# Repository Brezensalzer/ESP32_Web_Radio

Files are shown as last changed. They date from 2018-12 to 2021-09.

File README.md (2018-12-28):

This code is based on the great project from Nick Koumaris here: https://educ8s.tv/esp32-internet-radio/ .
There is also an instructable page: https://www.instructables.com/id/Internet-Radio-Using-an-ESP32/

Code changes:
* the station list is fetched on startup from a remote web server
* multitasking and buffering - the mp3 player code is running in a separate task (freeRTOS), the mp3 chunks are buffered in a queue
* Nextion HMI adapted to my 2.8" version of the display. Text is displayed dynamically with an art deco font. Buttons and a slider are used as controls (vs. physical buttons in the original project)
* Nextion display is connected to "Serial2" (ESP32 pins 16 RXD & 17 TXD) - "Serial" is connected to the USB converter and gives trouble when uploading a sketch.
* Station and volume control with rotary encoders

Used libraries:
* https://github.com/baldram/ESP_VS1053_Library
* https://github.com/itead/ITEADLIB_Arduino_Nextion
* Rotary encoder code from https://github.com/Edzelf/ESP32-Radio

Hardware:
* ESP32 board (Node32s)
* Nextion Display NX3224T028_011
* Level shifter 5V - 3.3V, 2 channels: Nextion runs on 5V, ESP32 (RX pin!) on 3.3V 
* MP3 module "LC Technology VS1003/1053 MP3 CODEC"
* Adafruit Stereo 2.1W Class D Audio Amplifier - TPA2012 (no noise!)
* Adafruit Speaker - 3" Diameter - 4 Ohm 3 Watt, 2x
* KY-040 Rotary Encoder, 2x

Plan:
* building a wooden artdeco enclosure: http://www.vintageradio.nl/radio%27s/rubis_type_72_engels.htm

3D Drawings:
* FreeCAD, step and stl files are now available.
* My first version will be 3D printed
* Youtube Video: https://youtu.be/TEc8J43VpVg

<p align="center">
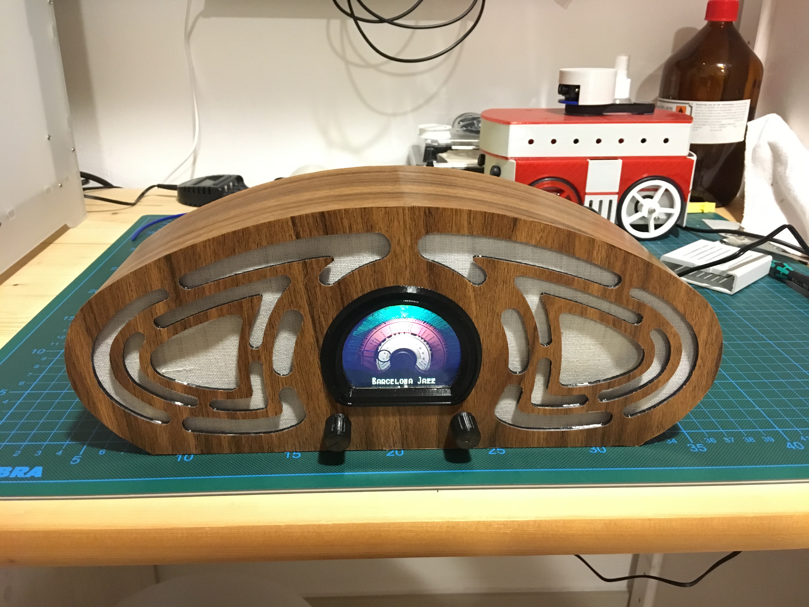
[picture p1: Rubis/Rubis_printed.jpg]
  
</p>

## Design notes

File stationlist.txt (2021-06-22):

B5 aktuell;http://br-b5aktuell-live.cast.addradio.de/br/b5aktuell/live/mp3/mid
BR Klassik;http://br-brklassik-live.cast.addradio.de/br/brklassik/live/mp3/mid
Bayern 2;http://br-br2-sued.cast.addradio.de/br/br2/sued/mp3/mid
Deutschlandfunk Kultur;http://st02.dlf.de/dlf/02/128/mp3/stream.mp3
Jazz Radio BCN;http://node-22.zeno.fm:80/u40kkya8hg8uv
Abacus Jazz;http://185.80.221.113:8034/stream
SmoothJazz;http://sj128.hnux.com/
City Jazz Radio;http://85.17.122.32:8252/stream

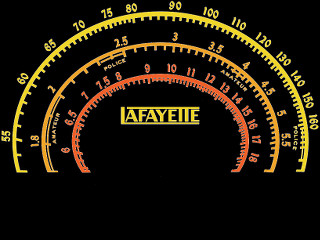
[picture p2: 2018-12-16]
GUI/lafayettedial.jpg

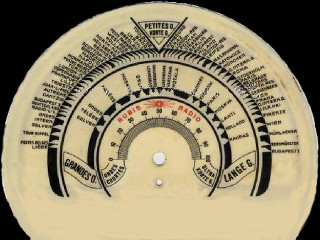
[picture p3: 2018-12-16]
GUI/rubis70_dial.jpg

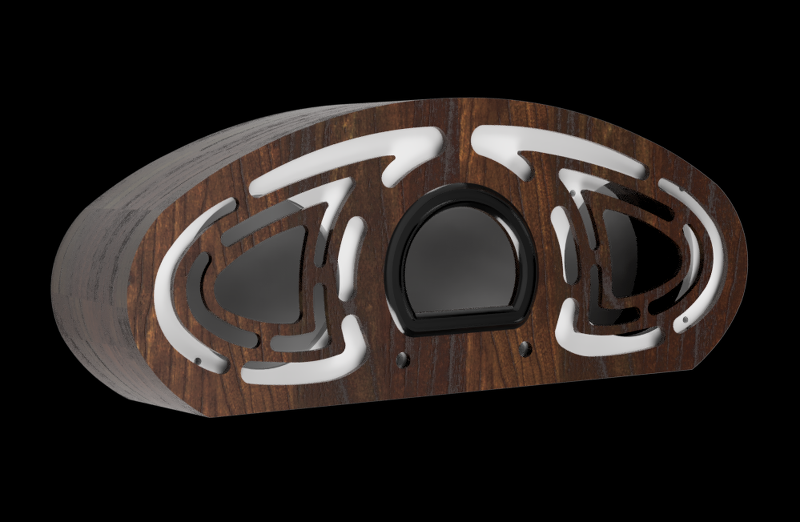
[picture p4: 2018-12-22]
Rubis/Rubis_70_render.png

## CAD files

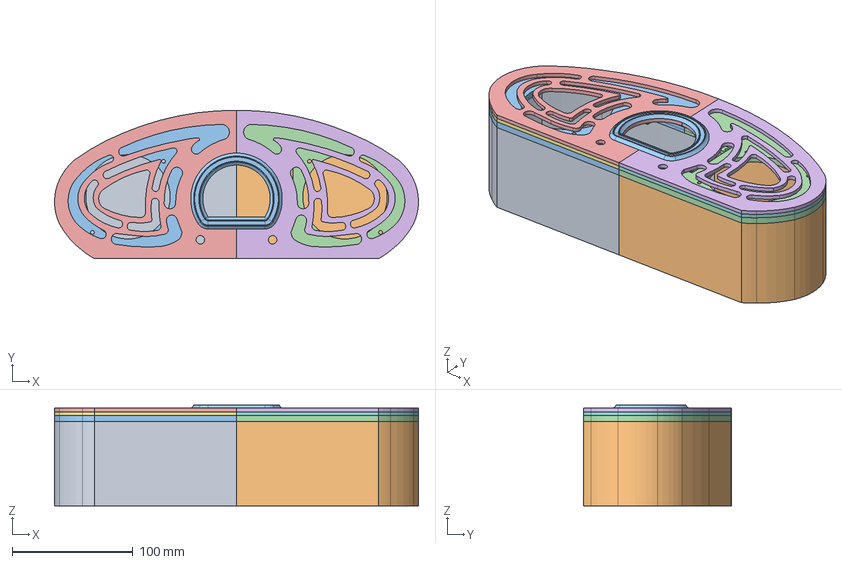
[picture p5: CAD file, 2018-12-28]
Rubis/rubis_korpus.FCStd
302.1 x 123.1 x 83.5 mm
Korpus_links
Korpus_rechts
Front_links
Front_rechts
Blende_links
Blende_rechts
Korpus_links001
Korpus_rechts001
Rückwand_links
Rückwand_rechts

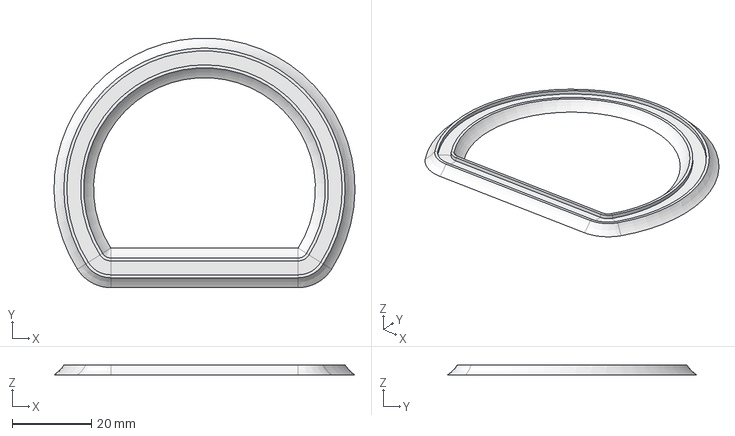
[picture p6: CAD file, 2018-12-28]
Rubis/Displayrahmen.step
76.0 x 62.9 x 2.50 mm

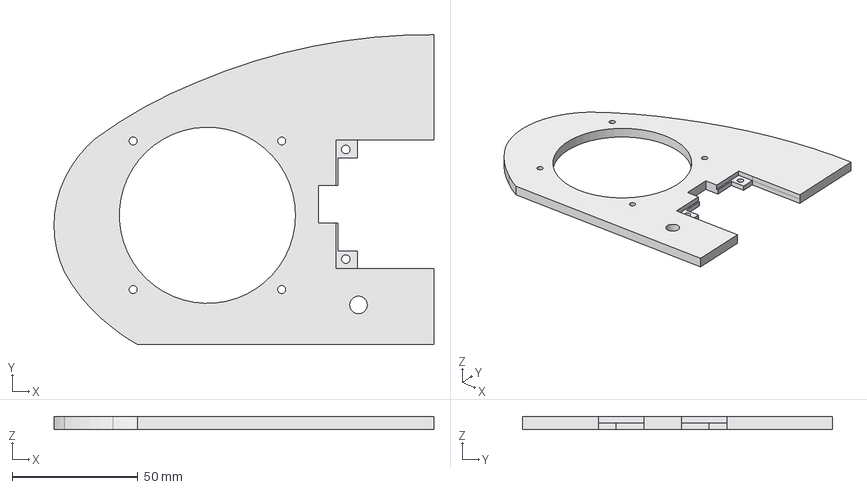
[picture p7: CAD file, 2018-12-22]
Rubis/Front_links.step
151.0 x 123.1 x 5.00 mm

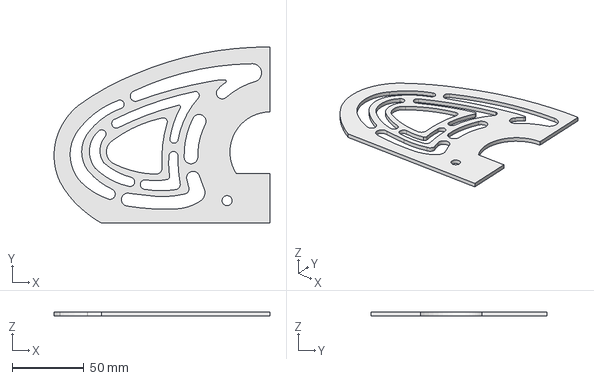
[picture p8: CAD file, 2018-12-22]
Rubis/Blende_links.step
151.0 x 123.1 x 3.00 mm

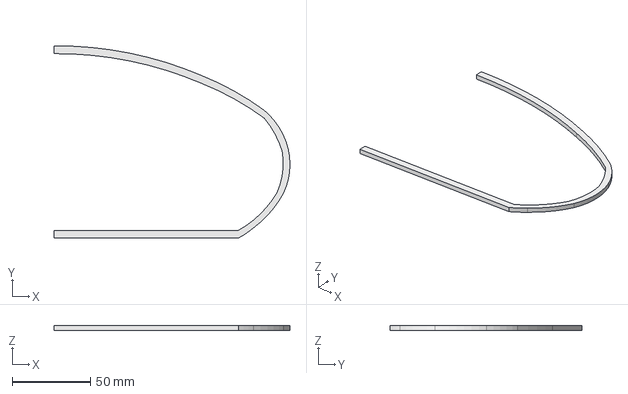
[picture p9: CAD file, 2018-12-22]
Rubis/Montage_rechts.step
151.0 x 123.1 x 3.00 mm

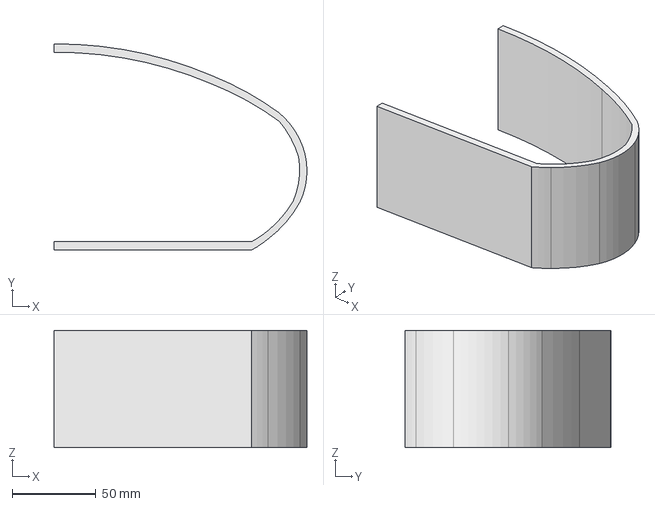
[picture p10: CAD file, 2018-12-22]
Rubis/Korpus_rechts.step
151.0 x 123.1 x 70.0 mm

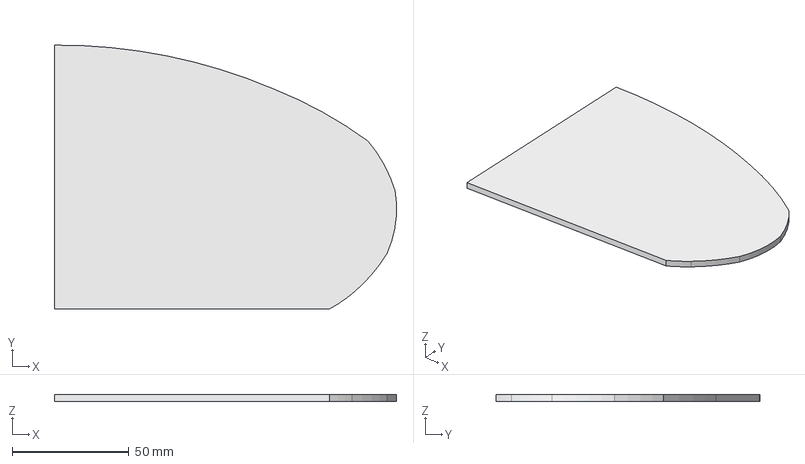
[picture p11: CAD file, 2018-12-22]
Rubis/Back_rechts.step
146.6 x 113.1 x 3.00 mm

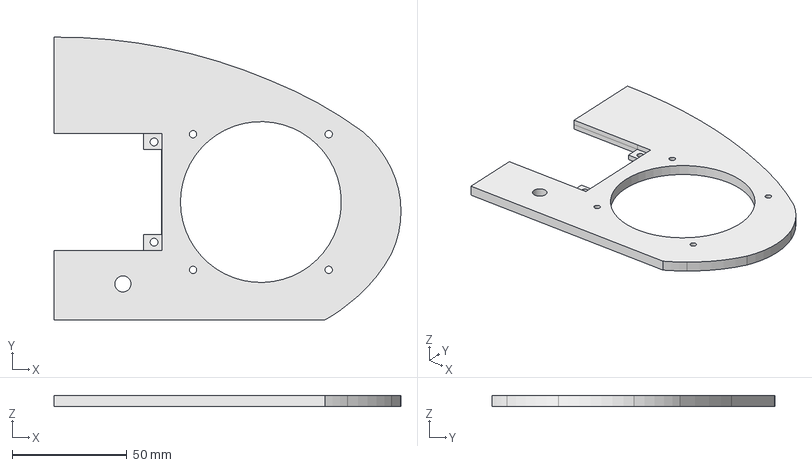
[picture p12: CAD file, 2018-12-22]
Rubis/Front_rechts.step
151.0 x 123.1 x 5.00 mm

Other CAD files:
Rubis/Montage_links.step
Rubis/Korpus_links.step
Rubis/Back_links.step
Rubis/Blende_rechts.step
Rubis/Back_links.stl
Rubis/Back_rechts.stl
Rubis/Blende_links.stl
Rubis/Blende_rechts.stl
Rubis/Displayrahmen.stl
Rubis/Front_links.stl
Rubis/Front_rechts.stl
Rubis/Korpus_links.stl
Rubis/Korpus_rechts.stl
Rubis/Montage_links.stl
Rubis/Montage_rechts.stl

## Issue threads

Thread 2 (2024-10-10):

The sketch doesn't compile

ovidiu169, 2024-10-10:
C:\Users\Ovidiu\Documents\Arduino\libraries\ESP32_Web_Radio-master\ESP32_Web_Radio\ESP32_Web_Radio.ino:15:10: fatal error: credentials.h: No such file or directory
   15 | #include <credentials.h>
      |          ^~~~~~~~~~~~~~~
compilation terminated.
exit status 1

Compilation error: credentials.h: No such file or directory

What can I do ?!?

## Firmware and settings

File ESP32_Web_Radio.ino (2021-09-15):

// ESP32_Web_Radio.ino
//
// Project based on
// ESP32 Internet Radio Project     v1.00 
// http://educ8s.tv/esp32-internet-radio

#include <VS1053.h>
#include <WiFi.h>
#include <WebServer.h>
#include <ESPmDNS.h>
#include <HTTPClient.h>
#include <esp_wifi.h>
#include <Nextion.h>
#include <Arduino.h>
#include <credentials.h>
#include "RadioStation.h"

#define DEBUG true
#define LOGSERVER      "192.168.1.4"
#define UDP_LOGGER
#include <SimpleUDPLogger.h>
const char* ssid = mySSID;
const char* pass = myPASSWORD;
const char* host = "esp32radio";

#define FILESYSTEM SPIFFS
#include <SPIFFS.h>
File fsUploadFile;
WebServer server(80);

//------------------------------------------------------------------------------
// mp3 module
//------------------------------------------------------------------------------
  #define VS1053_CS    32 
  #define VS1053_DCS   33  
  #define VS1053_DREQ  35 
  #define MIN_VOLUME  70
  #define MAX_VOLUME  100
  uint8_t volume = 82; // volume level 0-100
  uint8_t mp3buff[32];   // vs1053 likes 32 bytes at a time
  
  VS1053 player(VS1053_CS, VS1053_DCS, VS1053_DREQ);
  
  //------------------------------------------------------------------------------
  void initMP3Decoder()
  //------------------------------------------------------------------------------
    {
      player.begin();
      player.switchToMp3Mode(); // optional, some boards require this
      player.setVolume(volume);
    }

//------------------------------------------------------------------------------
// freertos multitasking and queueing
//------------------------------------------------------------------------------
  #define QUEUELENGTH 1024
  QueueHandle_t xQueueMp3;
  
  // Dimensions the buffer that the task being created will use as its stack.
  // NOTE:  This is the number of bytes the stack will hold, not the number of
  // words as found in vanilla FreeRTOS.
  #define STACK_SIZE 65536
  TaskHandle_t xHandle = NULL;
  
  //------------------------------------------------------------------------------
  void task_mp3play(void * pvParameters)
  //------------------------------------------------------------------------------
  {
    byte        mp3chunk[32];
    uint16_t    queue_depth;

    // loop forever
    while(true)
    {
        // Receive a message on the created queue.  Block for 10 ticks if a
        // message is not immediately available.
        if( xQueueReceive( xQueueMp3, &( mp3chunk ), ( TickType_t ) 10 ) )
        {
             // we now can consume mp3chunk
             player.playChunk(mp3chunk, 32);
             yield();
        }
    }
  }
  
  //------------------------------------------------------------------------------
  void mp3Flush()   // clear queue from previous station
  //------------------------------------------------------------------------------
  {
      char rc;
      while(rc != pdPASS)
          rc = xQueueReset(xQueueMp3);
  }

//------------------------------------------------------------------------------
// radio stations
//------------------------------------------------------------------------------
  StationList stations;

//------------------------------------------------------------------------------
// Nextion
//------------------------------------------------------------------------------
  // don't use UART0, conflict with sketch upload
  // use UART2 on Pins 16 RXD & 17 TXD
  // has to be changed in NexConfig.h (!)
  // #define nexSerial Serial2
  
  NexText t0 = NexText(0, 2, "t0");  

//------------------------------------------------------------------------------
// Rotary Encoders
// copied from https://github.com/Edzelf/ESP32-Radio
//------------------------------------------------------------------------------
  #define sv DRAM_ATTR static volatile    // alias

  //-----------------------------------------------------------------------------
  // radio station
  //-----------------------------------------------------------------------------
  #define ENC_STATION_CLK_PIN 21
  #define ENC_STATION_DT_PIN 22
  sv int16_t    rotationcount_station = 0;
  int16_t       oldcount_station = 0;

  //-----------------------------------------------------------------------------
  static void IRAM_ATTR isr_enc_station()
  //-----------------------------------------------------------------------------
  {
    sv uint32_t     old_state = 0x0001 ;                          // Previous state
    sv int16_t      locrotcount = 0 ;                             // Local rotation count
    uint8_t         act_state = 0 ;                               // The current state of the 2 PINs
    uint8_t         inx ;                                         // Index in enc_state
    sv const int8_t enc_states [] =                               // Table must be in DRAM (iram safe)
    { 0,                    // 00 -> 00
      -1,                   // 00 -> 01                           // dt goes HIGH
      1,                    // 00 -> 10
      0,                    // 00 -> 11
      1,                    // 01 -> 00                           // dt goes LOW
      0,                    // 01 -> 01
      0,                    // 01 -> 10
      -1,                   // 01 -> 11                           // clk goes HIGH
      -1,                   // 10 -> 00                           // clk goes LOW
      0,                    // 10 -> 01
      0,                    // 10 -> 10
      1,                    // 10 -> 11                           // dt goes HIGH
      0,                    // 11 -> 00
      1,                    // 11 -> 01                           // clk goes LOW
      -1,                   // 11 -> 10                           // dt goes HIGH
      0                     // 11 -> 11
    } ;
    // Read current state of CLK, DT pin. Result is a 2 bit binary number: 00, 01, 10 or 11.
    act_state = ( digitalRead ( ENC_STATION_CLK_PIN ) << 1 ) +
                  digitalRead ( ENC_STATION_DT_PIN ) ;
    inx = ( old_state << 2 ) + act_state ;                        // Form index in enc_states
    locrotcount += enc_states[inx] ;                              // Get delta: 0, +1 or -1
    if ( locrotcount == 4 )
    {
      rotationcount_station++ ;                                   // Divide by 4
      locrotcount = 0 ;
    }
    else if ( locrotcount == -4 )
    {
      rotationcount_station-- ;                                   // Divide by 4
      locrotcount = 0 ;
    }
    old_state = act_state ;                                       // Remember current status
  }

  //-----------------------------------------------------------------------------
  // volume
  //-----------------------------------------------------------------------------
  #define ENC_VOLUME_CLK_PIN 25
  #define ENC_VOLUME_DT_PIN 26
  sv int16_t    rotationcount_volume = volume;
  int16_t       oldcount_volume = 0;

  //-----------------------------------------------------------------------------
  static void IRAM_ATTR isr_enc_volume()
  //-----------------------------------------------------------------------------
  {
    sv uint32_t     old_state = 0x0001 ;                          // Previous state
    sv int16_t      locrotcount = 0 ;                             // Local rotation count
    uint8_t         act_state = 0 ;                               // The current state of the 2 PINs
    uint8_t         inx ;                                         // Index in enc_state
    sv const int8_t enc_states [] =  { 0,-1,1,0,1,0,0,-1,-1,0,0,1,0,1,-1,0 } ;
    // Read current state of CLK, DT pin. Result is a 2 bit binary number: 00, 01, 10 or 11.
    act_state = ( digitalRead ( ENC_VOLUME_CLK_PIN ) << 1 ) +
                  digitalRead ( ENC_VOLUME_DT_PIN ) ;
    inx = ( old_state << 2 ) + act_state ;                        // Form index in enc_states
    locrotcount += enc_states[inx] ;                              // Get delta: 0, +1 or -1
    if ( locrotcount == 4 )
    {
      rotationcount_volume++ ;                                    // Divide by 4
      locrotcount = 0 ;
    }
    else if ( locrotcount == -4 )
    {
      rotationcount_volume-- ;                                    // Divide by 4
      locrotcount = 0 ;
    }
    old_state = act_state ;                                       // Remember current status
  }

  //------------------------------------------------------------------------------
  void encoderStation_loop() 
  //------------------------------------------------------------------------------
  {
    //lets see if anything changed
    if ( rotationcount_station != oldcount_station )
    {
      if ( rotationcount_station > stations.numStations )
      {
        rotationcount_station = 0;
      }
      if ( rotationcount_station < 0 )
      {
        rotationcount_station = stations.numStations;
      }
      oldcount_station = rotationcount_station;
      stations.radioStation = rotationcount_station;  
    }
  }
  
  //------------------------------------------------------------------------------
  void encoderVolume_loop() 
  //------------------------------------------------------------------------------
  {
    //lets see if anything changed
    if ( rotationcount_volume != oldcount_volume )
    {
      if ( rotationcount_volume > MAX_VOLUME )
      {
        rotationcount_volume = MAX_VOLUME;
      }
      if ( rotationcount_volume < MIN_VOLUME )
      {
        rotationcount_volume = MIN_VOLUME;
      }
      oldcount_volume = rotationcount_volume;
      volume = (int) rotationcount_volume;
      player.setVolume(volume); 
      UDP_LOG_INFO("set volume to %lu", volume);
    }
  }

//------------------------------------------------------------------------------
// Network
//------------------------------------------------------------------------------
  HTTPClient http;
  WiFiClient * client; 

  //------------------------------------------------------------------------------
  void connectToWIFI()
  //------------------------------------------------------------------------------
  {
    if(DEBUG) {Serial.print("Connecting to Wifi");}
    WiFi.mode(WIFI_STA);
    WiFi.persistent(false);
    WiFi.begin(ssid, pass);
    while (WiFi.status() != WL_CONNECTED) 
    {
      if(DEBUG) {Serial.print(".");}
      delay(500);
    }
    if(DEBUG) {Serial.println("\nWifi connected");}  
  }

  //------------------------------------------------------------------------------
  void station_connect (int station_no ) 
  //------------------------------------------------------------------------------
  {
    if (http.connected())
    {
      http.end(); // stop old connection
    }
    boolean isConnected = false;

    char rc[4];
    int httpCode;  
    char url[250];
    const char* headerNames[] = { "Location" };
    String Location;
    int pos;
    
    if(DEBUG) { Serial.println(stations.station[station_no].label); }
    if(DEBUG) { Serial.println(stations.station[station_no].url); }
    UDP_LOG_INFO(stations.station[station_no].label);      
    UDP_LOG_INFO(stations.station[station_no].url);

    t0.setText(stations.station[station_no].label);                 
    
    //-------------------------------
    //--- check for http redirect ---
    //-------------------------------
    http.begin(stations.station[station_no].url);
    http.collectHeaders(headerNames, sizeof(headerNames)/sizeof(headerNames[0]));
    httpCode = http.GET();    

    //------- follow redirect -----------
    if (httpCode == 302)
    {
      if(DEBUG) { Serial.println("following redirect"); }
      UDP_LOG_INFO("following redirect");
      Location = http.header("Location");
      Location.toCharArray(url, Location.length()+1);
      if(DEBUG) { Serial.println(url); }
      UDP_LOG_INFO(url);

      http.end();
      http.begin(url);
      httpCode = http.GET();
    }
    //-------------------------------

    if (httpCode == HTTP_CODE_OK)
    {
      client = http.getStreamPtr();
      isConnected = true;
    }
    else
    {
      if(DEBUG) { Serial.println("connection to station failed"); }
      UDP_LOG_INFO("connection to station failed");
      t0.setText("Station Error");            
    }
  }

  //------------------------------------------------------------------------------
  void mp3stream()
  //------------------------------------------------------------------------------
  {
    uint16_t    queue_depth, queue_avail;
    uint16_t    num_chunks;
    
    // how many chunks are in the tcp buffer?
    num_chunks = client->available() / 32;

    // avoid queue overflow
    queue_depth = uxQueueMessagesWaiting(xQueueMp3);
    queue_avail = QUEUELENGTH - queue_depth;
    if (queue_avail < num_chunks)
    {
        num_chunks = queue_avail;
    }
    
    // fill queue with mp3 chunks
    while (num_chunks > 0)
    {
        uint8_t bytesread = client->read(mp3buff, 32);
        // Send a chunk.  Wait for 10 ticks for space to become
        // available if necessary.
        if( xQueueSend( xQueueMp3, ( void * ) &mp3buff, ( TickType_t ) 10 ) != pdPASS )
        { // Failed to post the message, even after 10 ticks.
          t0.setText("Error writing to queue!");
          UDP_LOG_ERROR("Error writing to queue!"); 
          if(DEBUG) { Serial.println("Error writing to queue!"); }
        } 
        num_chunks--;
    }
  }

//------------------------------------------------------------------------------
void importStationlist()
//------------------------------------------------------------------------------
{
    if(DEBUG) { Serial.println("Reading station list..."); }
    UDP_LOG_INFO("Reading station list...");
    t0.setText("Reading station list...");      
    File file = FILESYSTEM.open("/stationlist.txt", "r");
    if(!file)
    {
       if(DEBUG) { Serial.println("Error reading station list!"); }  
       UDP_LOG_INFO("Error reading station list!");
    }
    else
    {
      String payload = file.readString();
      stations.parseStations(payload);
    }
    file.close();  
}

//------------------------------------------------------------------------------
// Webserver
//------------------------------------------------------------------------------
  //------------------------------------------------------------------------------
  String formatBytes(size_t bytes)
  //------------------------------------------------------------------------------
  {
    if (bytes < 1024) {
      return String(bytes) + "B";
    } else if (bytes < (1024 * 1024)) {
      return String(bytes / 1024.0) + "KB";
    } else if (bytes < (1024 * 1024 * 1024)) {
      return String(bytes / 1024.0 / 1024.0) + "MB";
    } else {
      return String(bytes / 1024.0 / 1024.0 / 1024.0) + "GB";
    }
  }
  
  //------------------------------------------------------------------------------
  String getContentType(String filename)
  //------------------------------------------------------------------------------
  {
    if (server.hasArg("download")) {
      return "application/octet-stream";
    } else if (filename.endsWith(".htm")) {
      return "text/html";
    } else if (filename.endsWith(".html")) {
      return "text/html";
    } else if (filename.endsWith(".css")) {
      return "text/css";
    } else if (filename.endsWith(".js")) {
      return "application/javascript";
    } else if (filename.endsWith(".png")) {
      return "image/png";
    } else if (filename.endsWith(".gif")) {
      return "image/gif";
    } else if (filename.endsWith(".jpg")) {
      return "image/jpeg";
    } else if (filename.endsWith(".ico")) {
      return "image/x-icon";
    } else if (filename.endsWith(".xml")) {
      return "text/xml";
    } else if (filename.endsWith(".pdf")) {
      return "application/x-pdf";
    } else if (filename.endsWith(".zip")) {
      return "application/x-zip";
    } else if (filename.endsWith(".gz")) {
      return "application/x-gzip";
    }
    return "text/plain";
  }
  
  //------------------------------------------------------------------------------
  bool exists(String path)
  //------------------------------------------------------------------------------
  {
    bool yes = false;
    File file = FILESYSTEM.open(path, "r");
    if(!file.isDirectory()){
      yes = true;
    }
    file.close();
    return yes;
  }
  
  //------------------------------------------------------------------------------
  bool handleFileRead(String path)
  //------------------------------------------------------------------------------
  {
    if(DEBUG) { Serial.println("handleFileRead: " + path); }
    if (path.endsWith("/")) {
      path += "index.htm";
    }
    String contentType = getContentType(path);
    String pathWithGz = path + ".gz";
    if (exists(pathWithGz) || exists(path)) {
      if (exists(pathWithGz)) {
        path += ".gz";
      }
      File file = FILESYSTEM.open(path, "r");
      server.streamFile(file, contentType);
      file.close();
      return true;
    }
    return false;
  }
  
  //------------------------------------------------------------------------------
  void handleFileSave() {
  //------------------------------------------------------------------------------
    if (server.uri() != "/save") {
      return;
    }
    HTTPUpload& upload = server.upload();
    if (upload.status == UPLOAD_FILE_START) {
      String filename = upload.filename;
      if (!filename.startsWith("/")) {
        filename = "/" + filename;
      }
      if(DEBUG) { Serial.print("handleFileUpload Name: "); Serial.println(filename); }
      fsUploadFile = FILESYSTEM.open(filename, "w");
      filename = String();
    } else if (upload.status == UPLOAD_FILE_WRITE) {
      if (fsUploadFile) {
        fsUploadFile.write(upload.buf, upload.currentSize);
      }
    } else if (upload.status == UPLOAD_FILE_END) {
      if (fsUploadFile) {
        fsUploadFile.close();
      }
      if(DEBUG) { Serial.print("handleFileUpload Size: "); Serial.println(upload.totalSize); }
      UDP_LOG_INFO("stationlist.txt saved");
      importStationlist();
    }
  }
  
  //------------------------------------------------------------------------------
  void initWebserver()
  //------------------------------------------------------------------------------
  {
    FILESYSTEM.begin();
    {
      File root = FILESYSTEM.open("/");
      File file = root.openNextFile();
      while(file){
          String fileName = file.name();
          size_t fileSize = file.size();
          if(DEBUG) { Serial.printf("FS File: %s, size: %s\n", fileName.c_str(), formatBytes(fileSize).c_str()); }
          file = root.openNextFile();
      }
      if(DEBUG) { Serial.printf("\n"); }
    }
  
    MDNS.begin(host);
    if(DEBUG) { 
      Serial.print("Open http://");
      Serial.println(host);
    }
    
    server.on("/save", HTTP_POST, []() {
      server.send(200, "text/plain", "");
    }, handleFileSave);

  
    //called when the url is not defined here
    //use it to load content from FILESYSTEM
    server.onNotFound([]() {
      if (!handleFileRead(server.uri())) {
        server.send(404, "text/plain", "FileNotFound");
      }
    });
  
    server.begin();
    if(DEBUG) { Serial.println("Webserver started."); }
  }
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
void loop() 
{
    encoderStation_loop();
    encoderVolume_loop();

    // switch radio station
    if(stations.radioStation!=stations.previousRadioStation)
    {
        vTaskSuspend( xHandle );      // suspend mp3 player task
        mp3Flush();                   // clear mp3 queue from previous station
        station_connect(stations.radioStation);
        stations.previousRadioStation = stations.radioStation;
        mp3stream();  // prefill Queue
        vTaskResume( xHandle ); 
    }

    // read tcp stream and fill queue  
    mp3stream();

    // Webserver
    server.handleClient();

    // house keeping
    yield();
}

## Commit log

2018-12-16 exchanged rotary encoder code. It works :o)
2018-12-22 added 3D model of th e Rubis art deco radio
    [Back_links.step, Back_links.stl, Back_rechts.step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]
2018-12-22 added missing stl file
    [Displayrahmen.stl]
2018-12-28 fixed bezel dimension
    [Displayrahmen.step, Displayrahmen.stl, rubis_korpus.FCStd]
2018-12-28 added photo of 3D printed Rubis radio
2019-01-03 forked sketch for rotary encoders only version
2021-09-15 fixed url lengths up to 250 chars
    [ESP32_Web_Radio.ino]
